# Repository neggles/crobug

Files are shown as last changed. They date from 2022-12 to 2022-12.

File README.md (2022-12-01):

# crobug

### Render:

KiCad raytraced main board render
KiCad raytraced top board render

## y tho

cause you can't get suzyqable anymore

will add more details to this readme later

## Repository Structure
- `crobug` contains a suzy-q-alike adapter with a built in usb hub to give you both CCD and OTG gadget access at the same time
- `crobug-direct` foregoes the usb hub in service of being cheaper and easier to assemble, and also triggers BC1.2 mode for 1.5A charging
- `crobug-host` is the same as `crobug-direct` but with a host-mode micro-B connector for booting from a flash drive while using CCD
- `libraries/crobug.pretty` contains board-specific footprints
- `libraries/crobug.kicad_sym` contains board-specific symbols
- `libraries/shapes3D` contains board-specific STEP models (and a few extra)

## Building

### **building most likely does not work at the moment.** 
(I need to update kikit stuff to deal with KiCad 6 and also actually specify board dimensions, panel tabs etc still.)

Simply call `make` in the top-top level directory. The `build` directory will then contain:

- the main board and top board
- A panelized version of said boards
- zipped gerbers for the boards you can directly use for manufacturing

### Credit where it's due:

Makefile uses [Jan Mrázek](https://github.com/yaqwsx)'s [KiKit](https://github.com/yaqwsx/KiKit),
which I cannot recommend enough and will need to be available before running `make`

Jan's [jlcparts](https://yaqwsx.github.io/jlcparts/) app was also extremely useful in narrowing 
down part choices based on what JLCPCB have available.

### License
<a rel="license" href="http://creativecommons.org/licenses/by-sa/4.0/">

</a><br /><span xmlns:dct="http://purl.org/dc/terms/" property="dct:title">crobug</span> by
<a xmlns:cc="http://creativecommons.org/ns#" href="https://github.com/neggles" property="cc:attributionName" rel="cc:attributionURL">neggles</a>
is licensed under a
<a rel="license" href="http://creativecommons.org/licenses/by-sa/4.0/">
Creative Commons Attribution-ShareAlike 4.0 International License
</a>

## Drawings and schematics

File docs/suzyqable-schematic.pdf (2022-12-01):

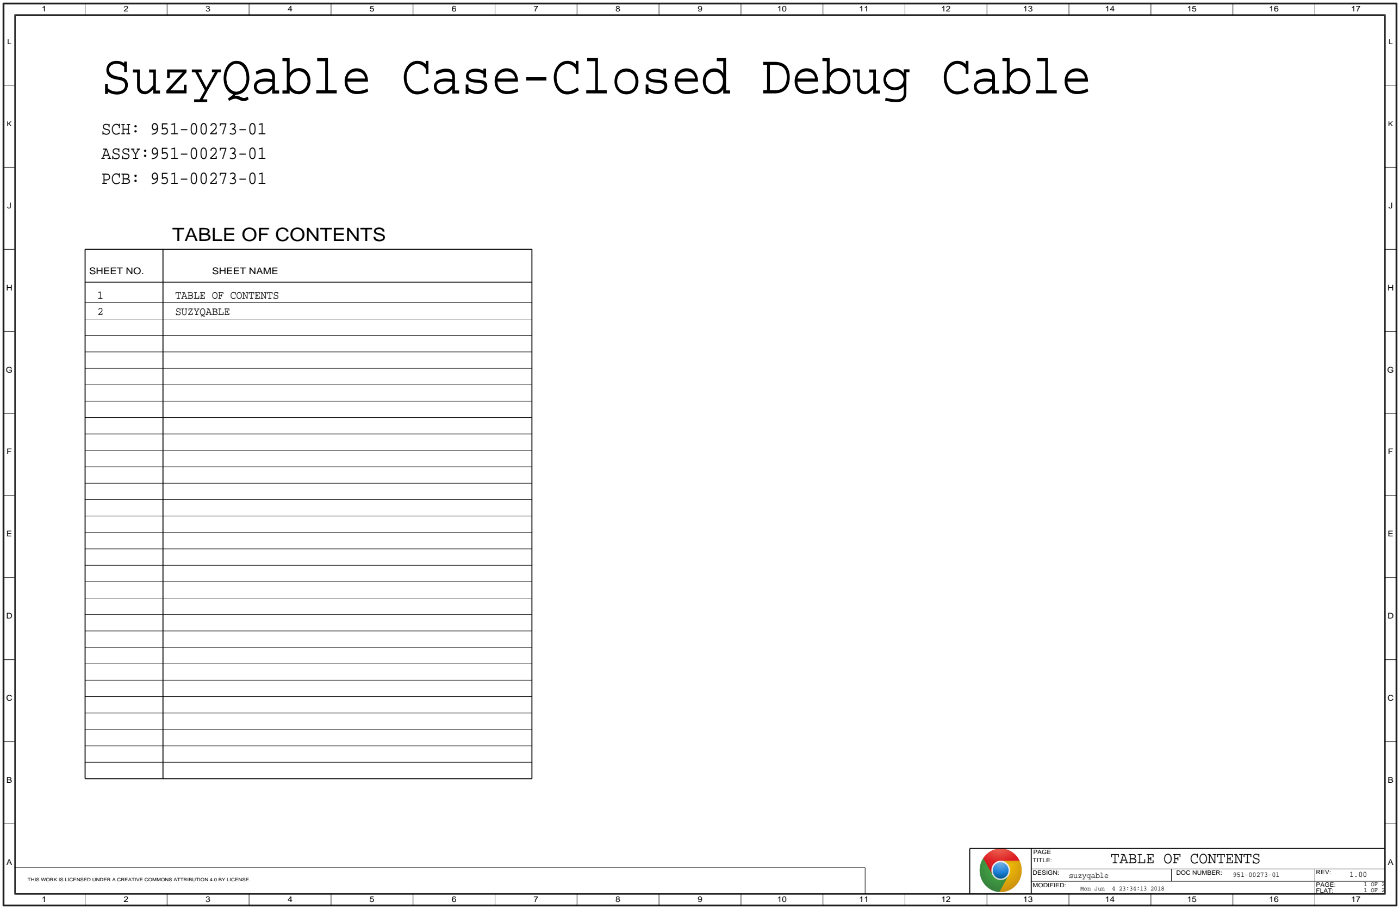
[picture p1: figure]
Mon Jun 4 23:34:13 2018; TABLE OF CONTENTS; SUZYQABLE; ASSY:951-00273-01 PCB: 951-00273-01; SCH: 951-00273-01; SuzyQable Case-Closed Debug Cable; suzyqable; MODIFIED:; REV:; PAGE:; FLAT:; DOC NUMBER:; PAGE TITLE:; DESIGN:; SHEET NO.; SHEET NAME

THIS WORK IS LICENSED UNDER A CREATIVE COMMONS ATTRIBUTION 4.0 BY LICENSE.

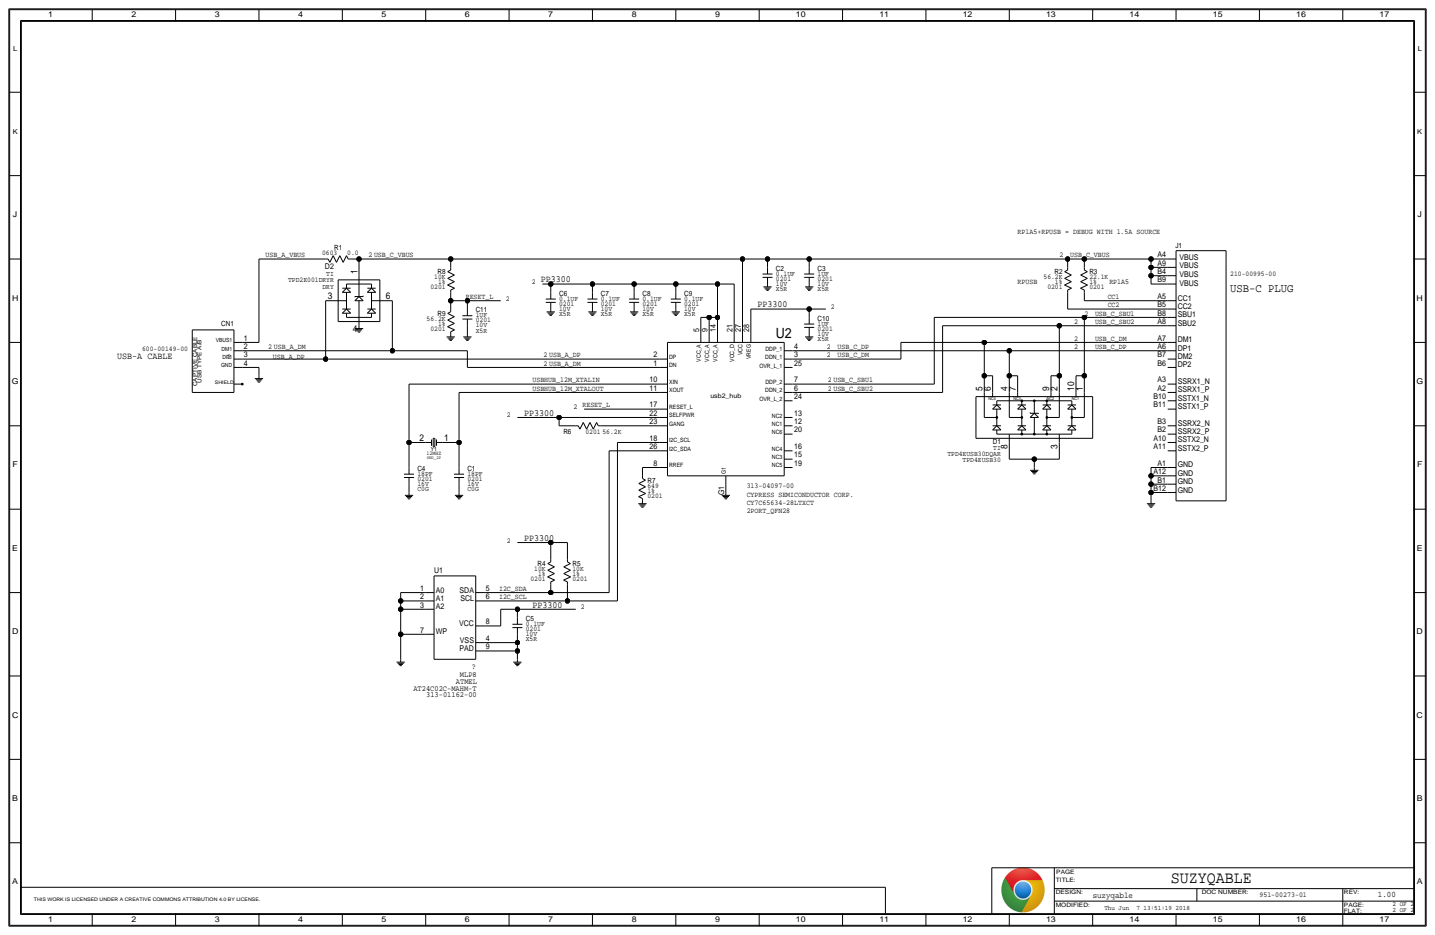
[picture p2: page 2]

RP1A5+RPUSB = DEBUG WITH 1.5A SOURCE

2 | A8 USB_C_SBU2
2 | USB_C_DM A7

USB-A CABLE ⁶⁰⁰⁻⁰⁰¹⁴⁹⁻⁰⁰

THIS WORK IS LICENSED UNDER A CREATIVE COMMONS ATTRIBUTION 4.0 BY LICENSE.

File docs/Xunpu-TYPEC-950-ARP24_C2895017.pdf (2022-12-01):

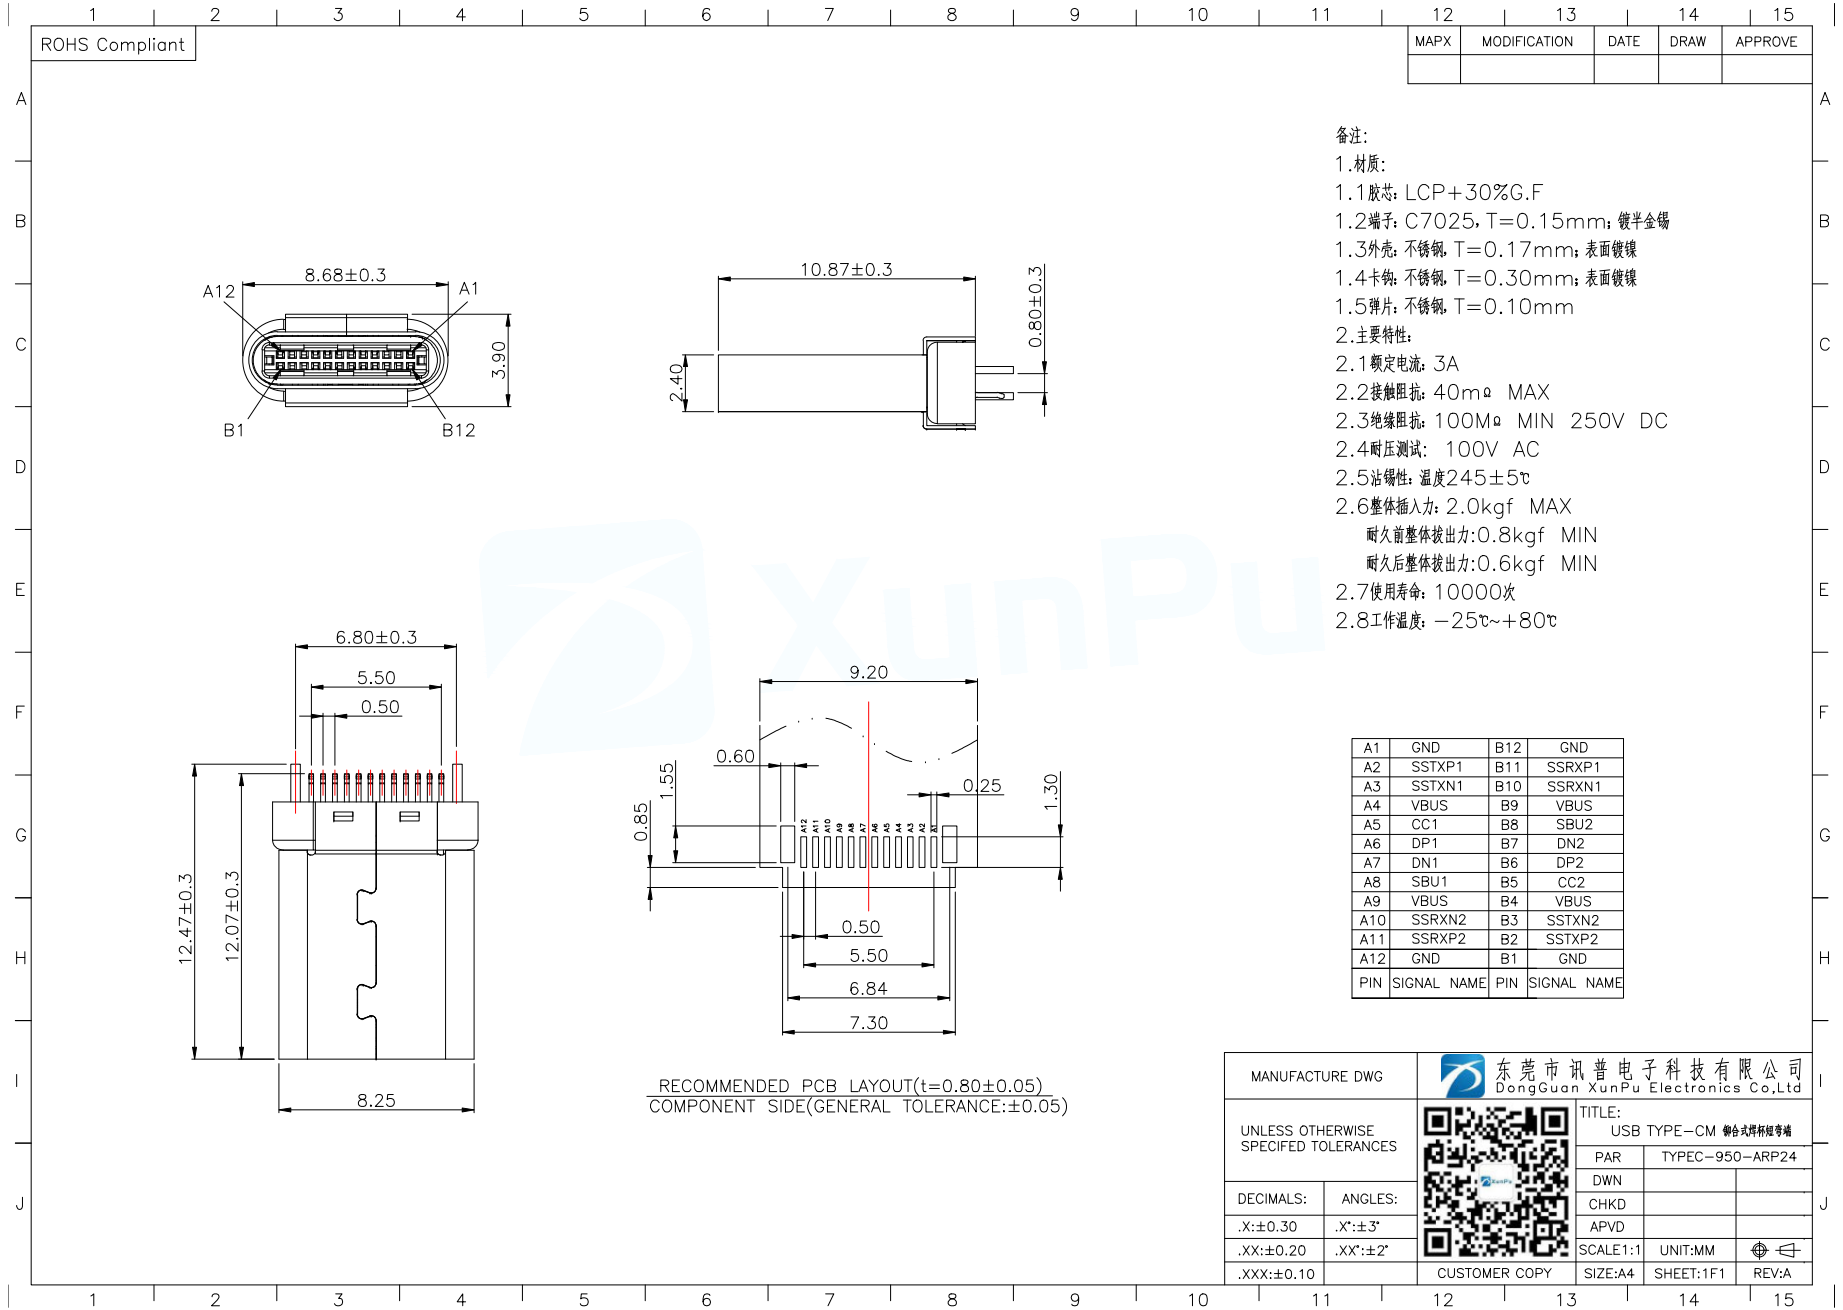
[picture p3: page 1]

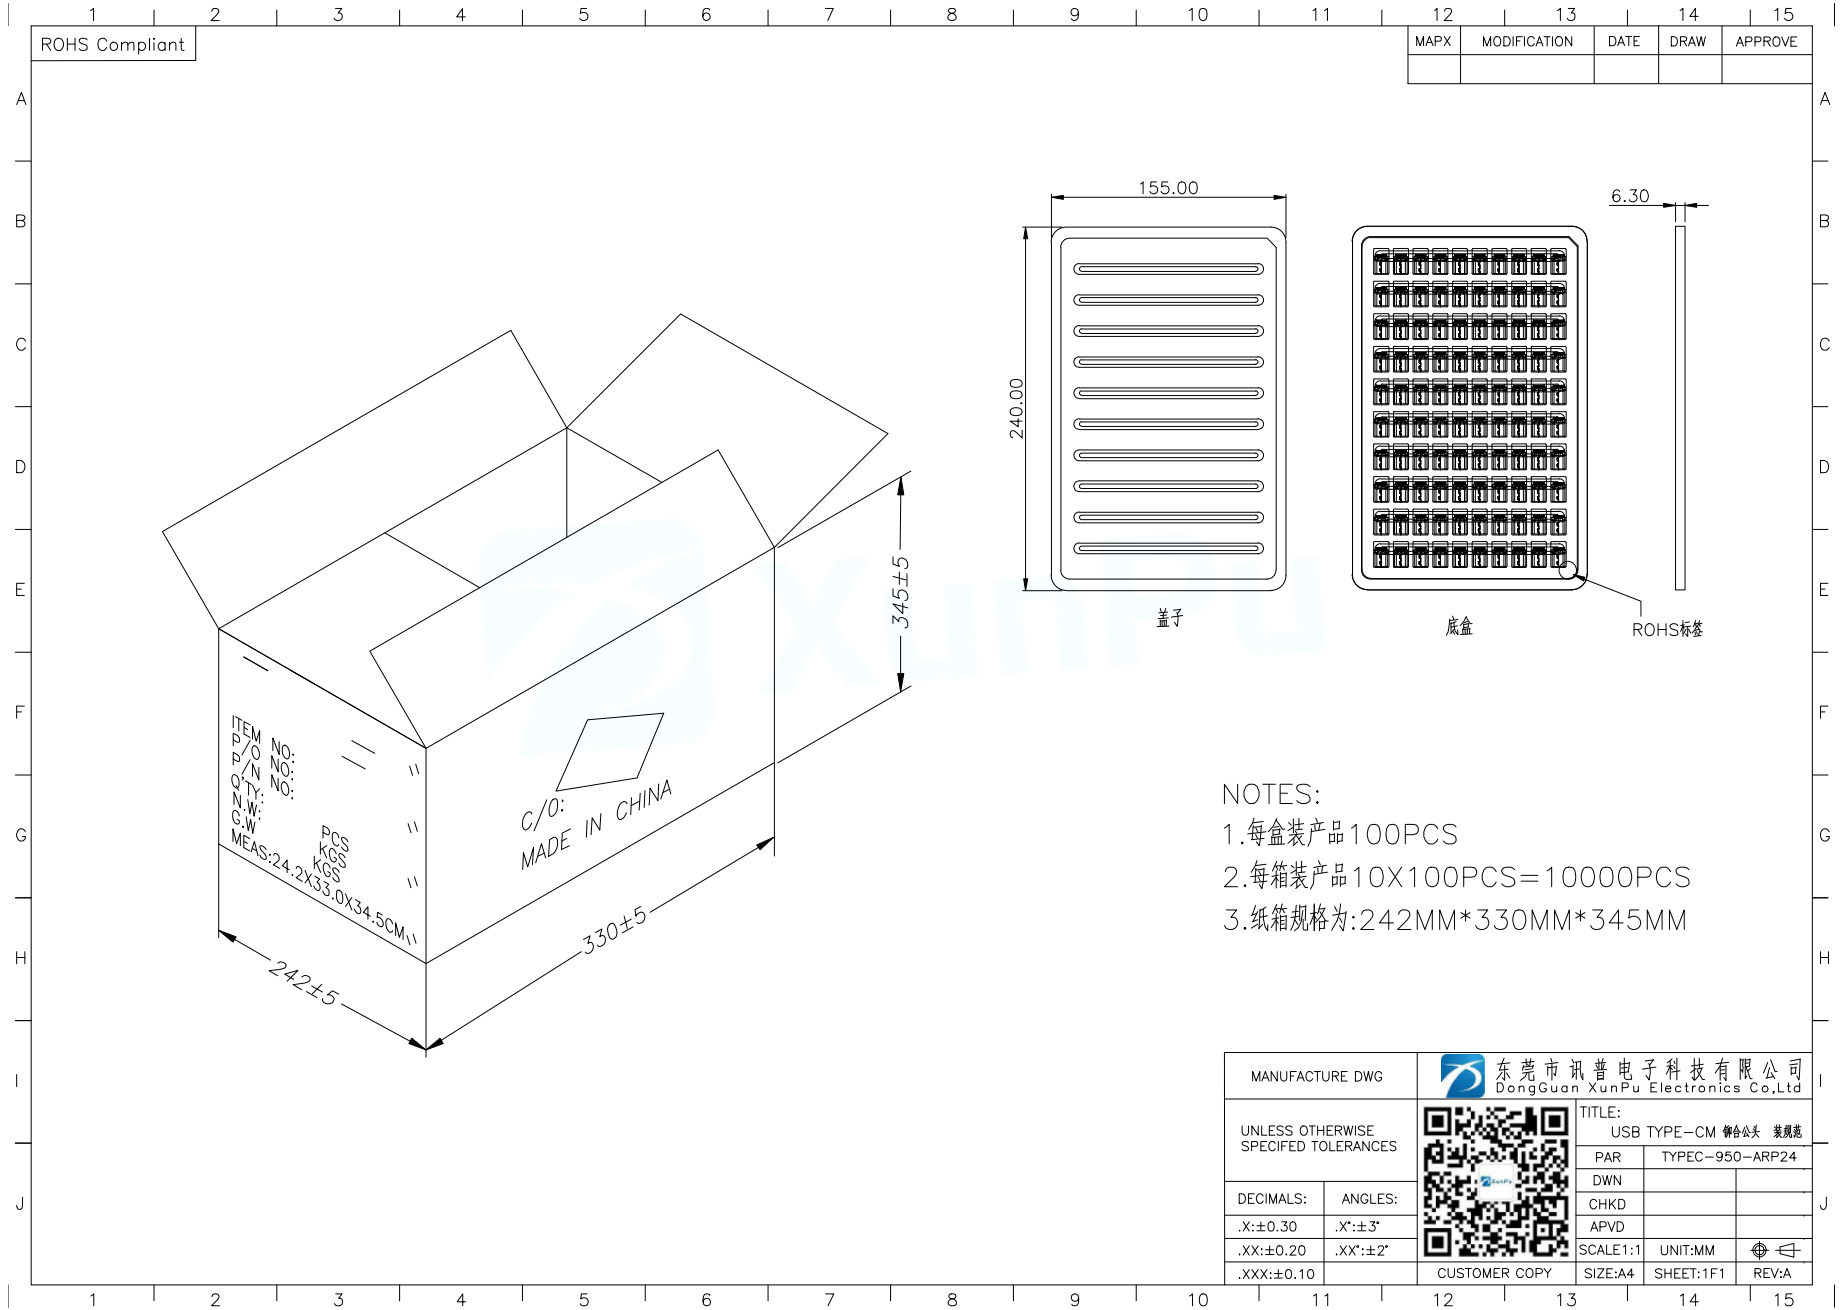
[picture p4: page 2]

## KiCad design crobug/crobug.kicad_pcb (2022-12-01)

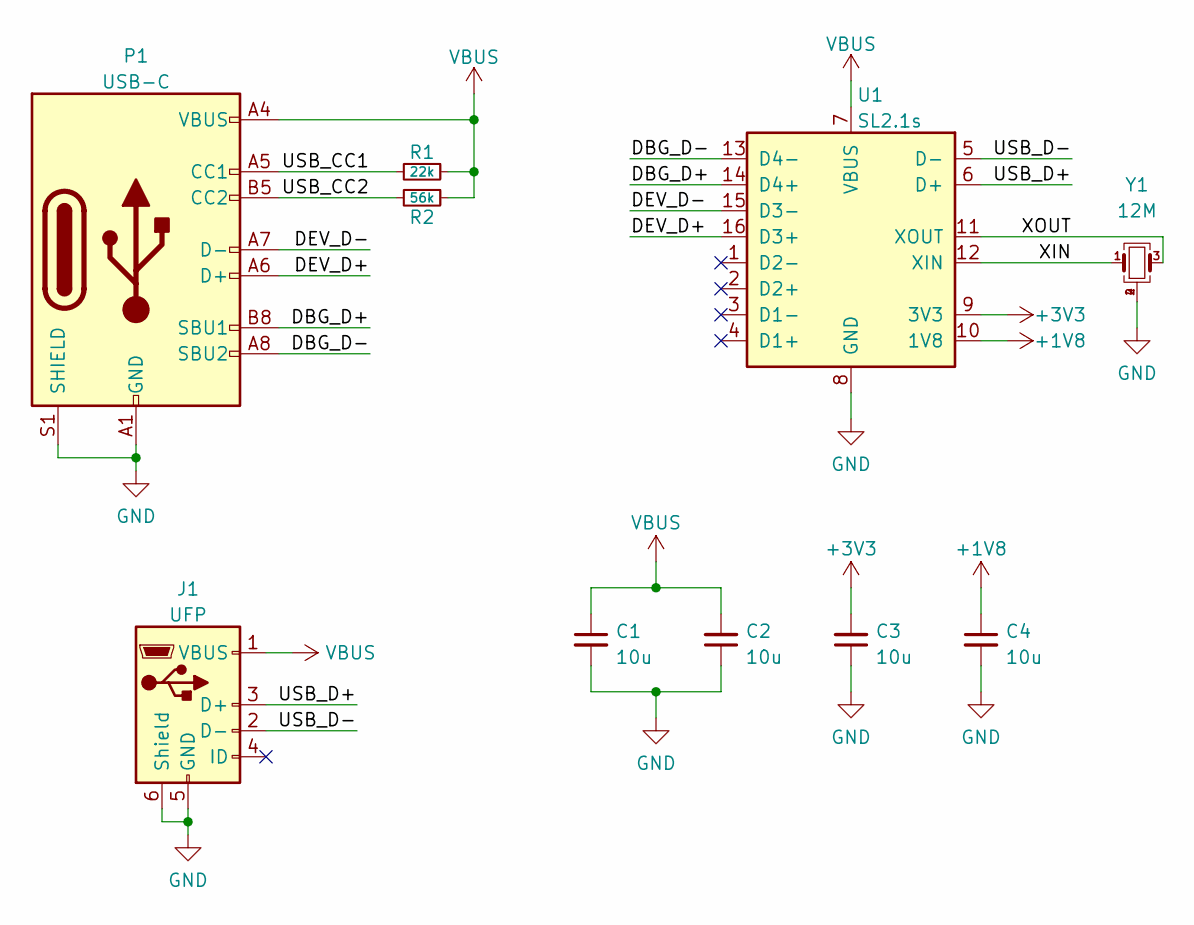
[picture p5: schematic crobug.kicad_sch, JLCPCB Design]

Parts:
C1, C2, C3, C4: 10u; C_0603_1608Metric
J1: UFP; Micro-USB_Xunpu-MU-109-ARY-C720609_AndVariants
P1: USB-C; USB_C_Plug_Xunpu_TYPEC-950-ARP24
R1: 22k; R_0603_1608Metric
R2: 56k; R_0603_1608Metric
U1: SL2.1s; SSOP-16_4.6x26.mm_P0.53mm; LCSC C2684433
Y1: 12M; Crystal_SMD_2520-4Pin_2.5x2.0mm; LCSC C9002

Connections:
+1V8: C4.1, U1.10 (1V8)
+3V3: C3.2, U1.9 (3V3)
/DBG_D+: P1.B8 (SBU1), U1.14 (D4+)
/DBG_D-: P1.A8 (SBU2), U1.13 (D4-)
/DEV_D+: P1.A6 (D+), U1.16 (D3+)
/DEV_D-: P1.A7 (D-), U1.15 (D3-)
/USB_CC1: P1.A5 (CC1), R1.2
/USB_CC2: P1.B5 (CC2), R2.2
/USB_D+: J1.3 (D+), U1.6 (D+)
/USB_D-: J1.2 (D-), U1.5 (D-)
/XIN: U1.12 (XIN), Y1.1
/XOUT: U1.11 (XOUT), Y1.3
GND: C1.2, C2.1, C3.1, C4.2, J1.5 (GND), J1.6 (Shield), P1.A1 (GND), P1.A12 (GND), P1.B1 (GND), P1.B12 (GND), P1.S1 (SHIELD), U1.8 (GND), Y1.2, Y1.4
VBUS: C1.1, C2.2, J1.1 (VBUS), P1.A4 (VBUS), P1.A9 (VBUS), P1.B4 (VBUS), P1.B9 (VBUS), R1.1, R2.1, U1.7 (VBUS)

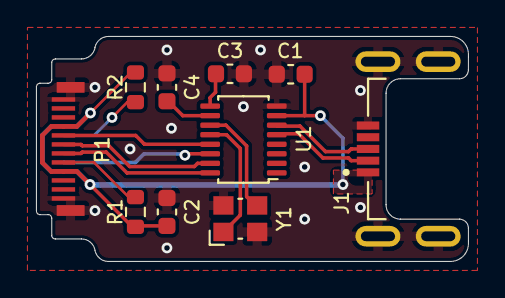
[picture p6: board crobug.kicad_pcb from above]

Board: 2 copper layers, 24.0 x 12.5 mm, 10 parts (0 on the bottom side), 14 nets.

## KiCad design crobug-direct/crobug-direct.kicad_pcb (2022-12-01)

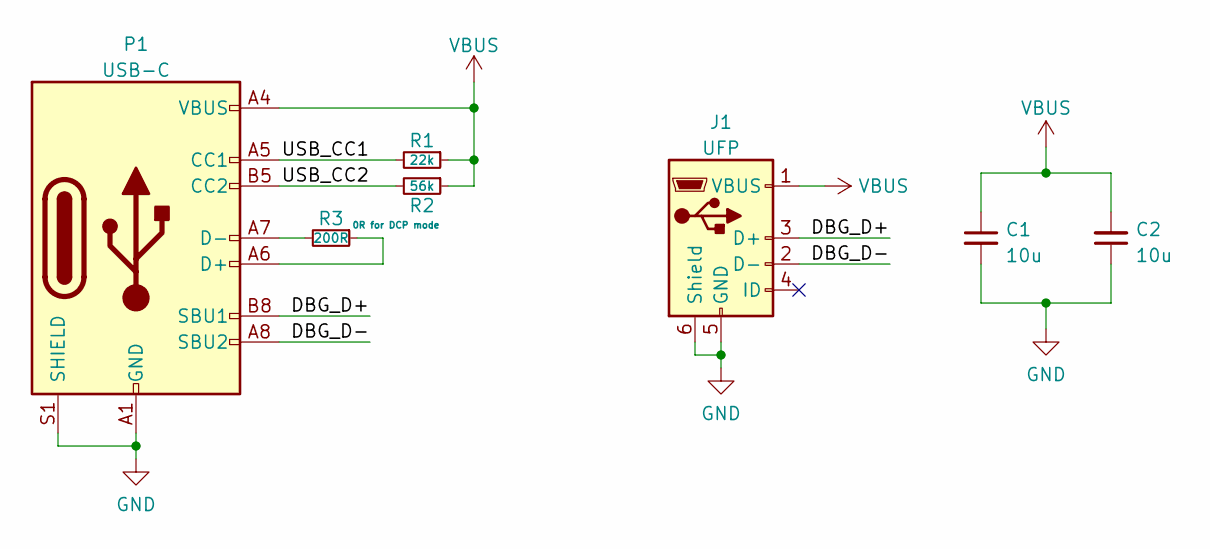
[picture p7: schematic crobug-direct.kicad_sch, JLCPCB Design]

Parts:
C1, C2: 10u; C_0603_1608Metric
J1: UFP; Micro-USB_Xunpu-MU-109-ARY-C720609_AndVariants
P1: USB-C; USB_C_Plug_Xunpu_TYPEC-950-ARP24
R1: 22k; R_0603_1608Metric
R2: 56k; R_0603_1608Metric
R3: 200R; R_0603_1608Metric

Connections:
/DBG_D+: J1.3 (D+), P1.B8 (SBU1)
/DBG_D-: J1.2 (D-), P1.A8 (SBU2)
/USB_CC1: P1.A5 (CC1), R1.2
/USB_CC2: P1.B5 (CC2), R2.2
GND: C1.2, C2.1, J1.5 (GND), J1.6 (Shield), P1.A1 (GND), P1.A12 (GND), P1.B1 (GND), P1.B12 (GND), P1.S1 (SHIELD)
unnamed: P1.A6 (D+), R3.1
unnamed: P1.A7 (D-), R3.2
VBUS: C1.1, C2.2, J1.1 (VBUS), P1.A4 (VBUS), P1.A9 (VBUS), P1.B4 (VBUS), P1.B9 (VBUS), R1.1, R2.1

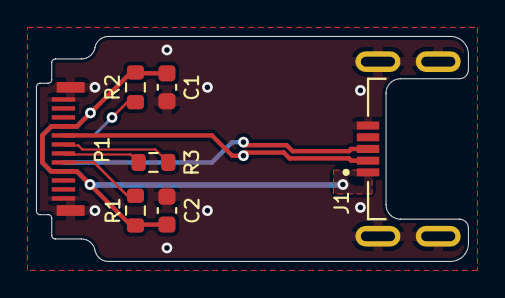
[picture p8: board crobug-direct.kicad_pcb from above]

Board: 2 copper layers, 24.0 x 12.5 mm, 7 parts (0 on the bottom side), 8 nets.
